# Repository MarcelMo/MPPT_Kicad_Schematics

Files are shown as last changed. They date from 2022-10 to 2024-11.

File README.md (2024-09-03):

Based on https://www.instructables.com/DIY-1kW-MPPT-Solar-Charge-Controller/
Since I wanted to be able to change the board layout and to test KiCad I decided to give this "conversion" a try.

- I removed the keyboard pullups, they are not needed when activating the internal pullup. And I prefer switching to ground anyway, so I can use 5V for the display and the keyboard.
- I changed the footprint of the screw terminals, since I did not find any other (trustworthy) 50A capable terminal. https://www.degson.com/content/details_552_880568.html
- Added JTAG interface
- Added a SD card and IIC socket, mainly for a RTC module. Should allow for much better offline logging.
- Switched to 1.27mm pitch smd connector. No need for 2.54mm. Just uses up too much space - on both sides of the board. Also added a few spare IOs and IIC.
- Fan driver transistor. ToDo: Maybe better switch +, and not GND. Although switching ground allows for more flexibility regarding fan voltage.
- Had to divide GND into GND and GND2, so I could add the GND copper bar to the schematics and the layout without getting too hacky... Found no better "KiCad way"
- 3D models are almost complete. SD card is not perfect.
- Switched to USB-C

3D VRML preview: https://marcelmo.github.io/MPPT_Kicad_Schematics/ (Thanks to https://easyw.github.io/vrm360/ )
MPPT_Charger_top_view
MPPT_Charger_bottom_view

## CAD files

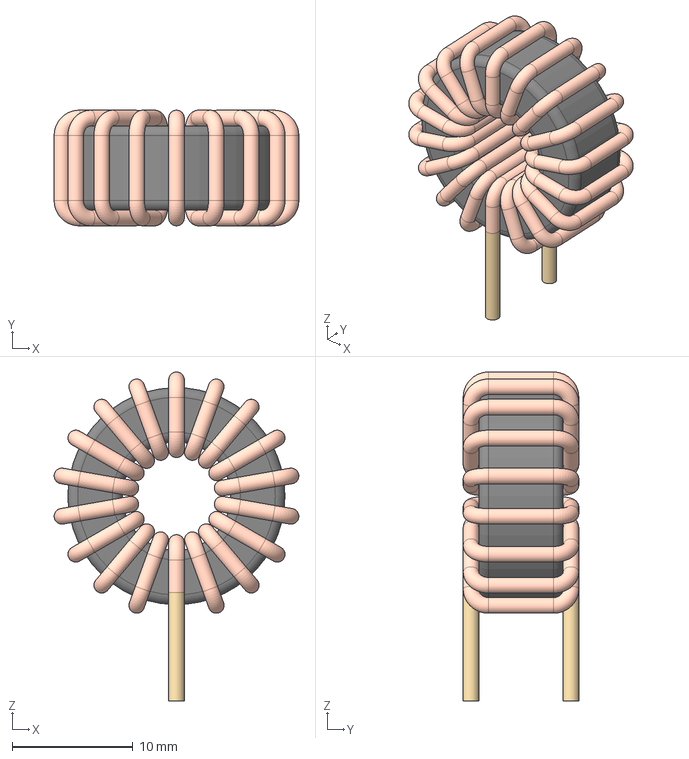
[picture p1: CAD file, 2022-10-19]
3D/torroid_inductor.step
20.3 x 9.60 x 27.3 mm

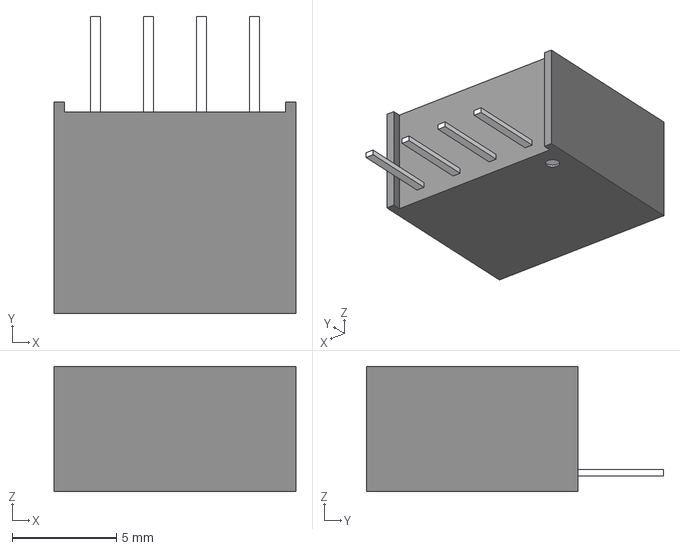
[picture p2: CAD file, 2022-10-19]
3D/B_S-1WR3.step
11.6 x 14.3 x 6.00 mm

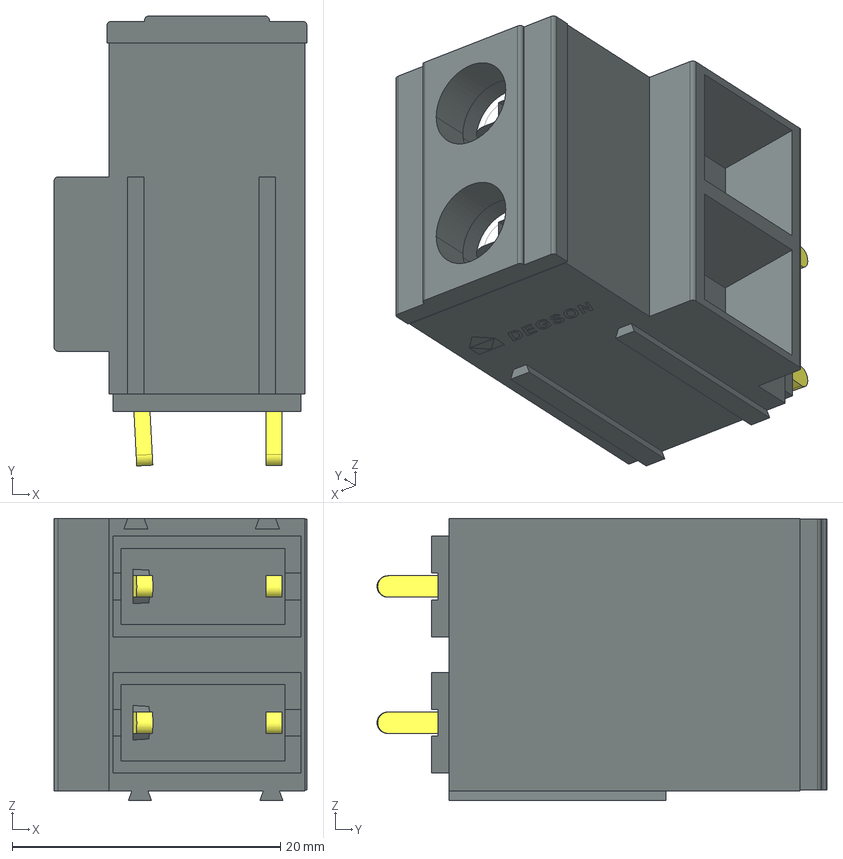
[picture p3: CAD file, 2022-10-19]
3D/DG135T-10.16-XXP-1Y-00A(H).step
18.9 x 33.6 x 21.0 mm

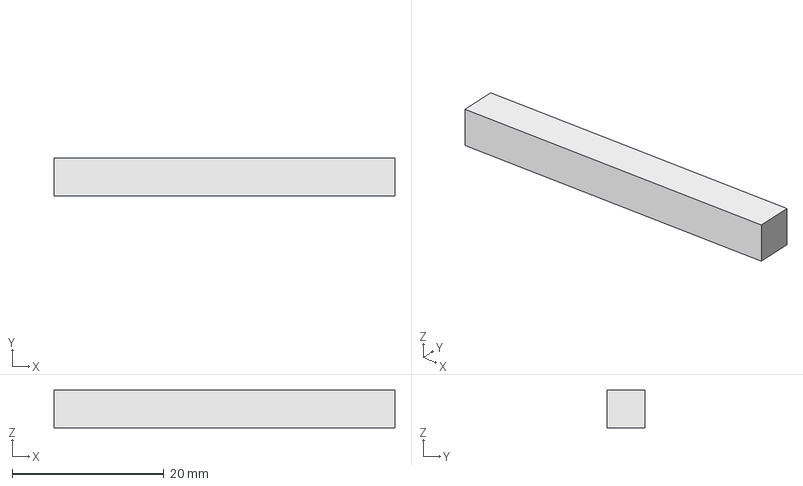
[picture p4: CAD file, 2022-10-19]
3D/bar.step
45.0 x 5.00 x 5.00 mm

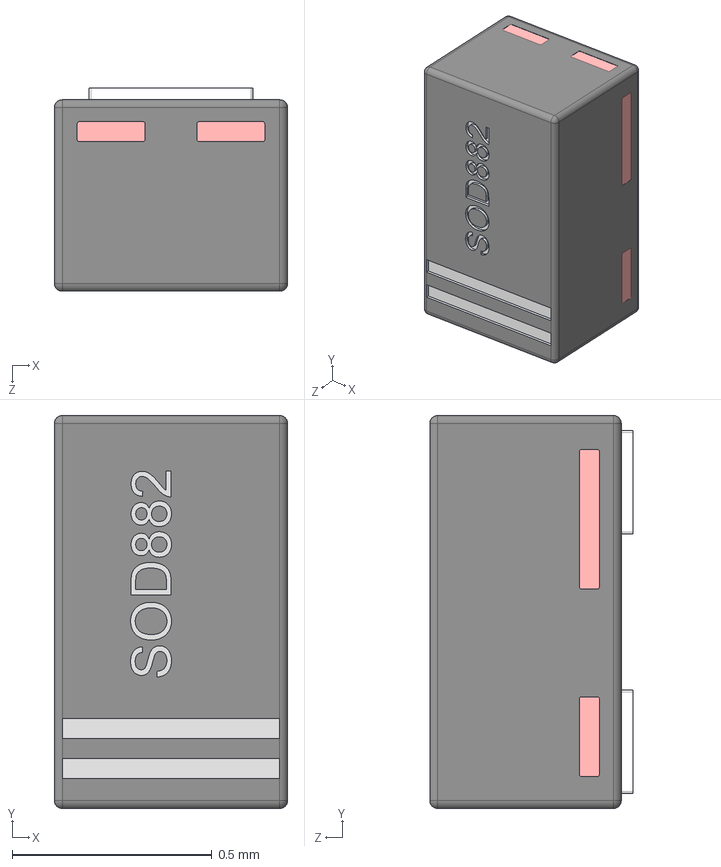
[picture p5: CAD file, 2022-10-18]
3D/SOD882-1.step
0.585 x 0.985 x 0.51 mm

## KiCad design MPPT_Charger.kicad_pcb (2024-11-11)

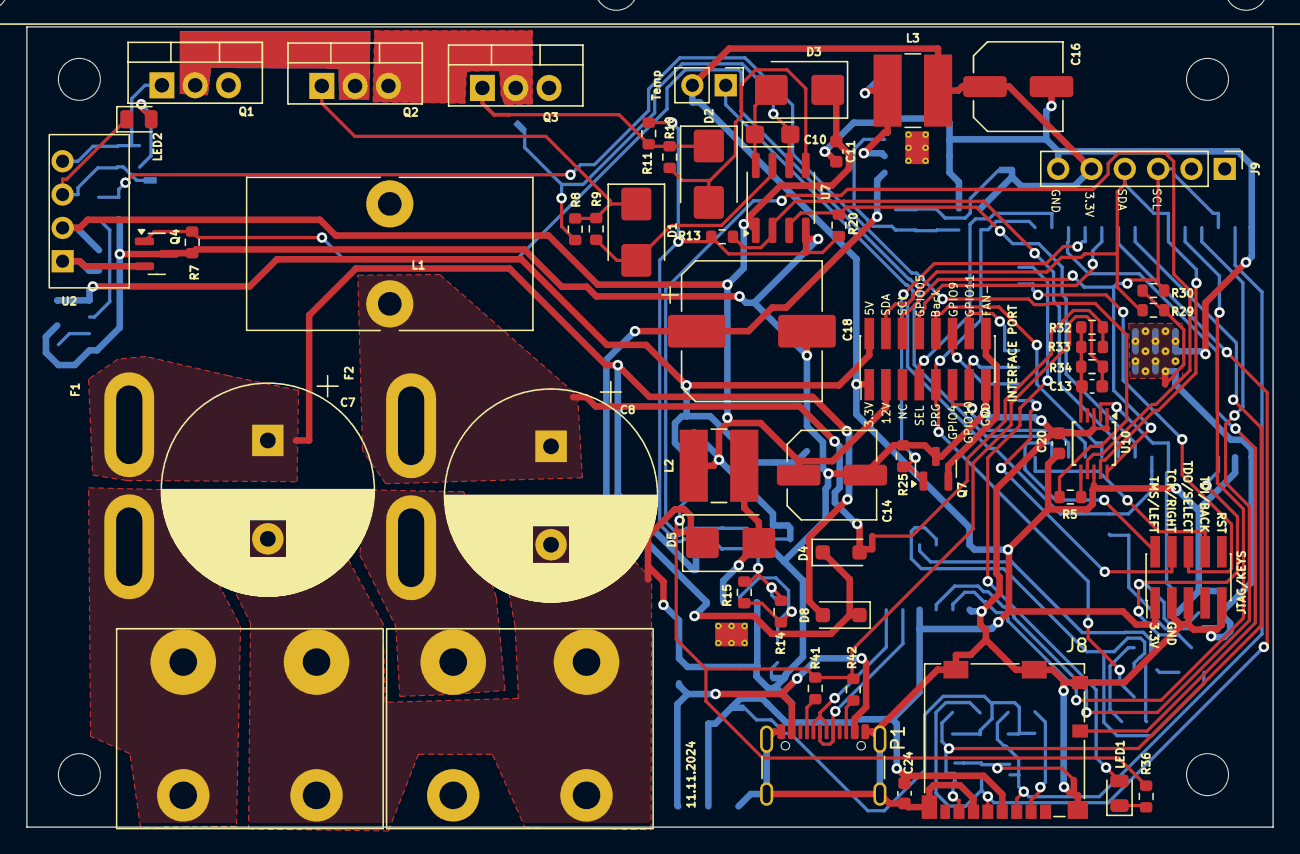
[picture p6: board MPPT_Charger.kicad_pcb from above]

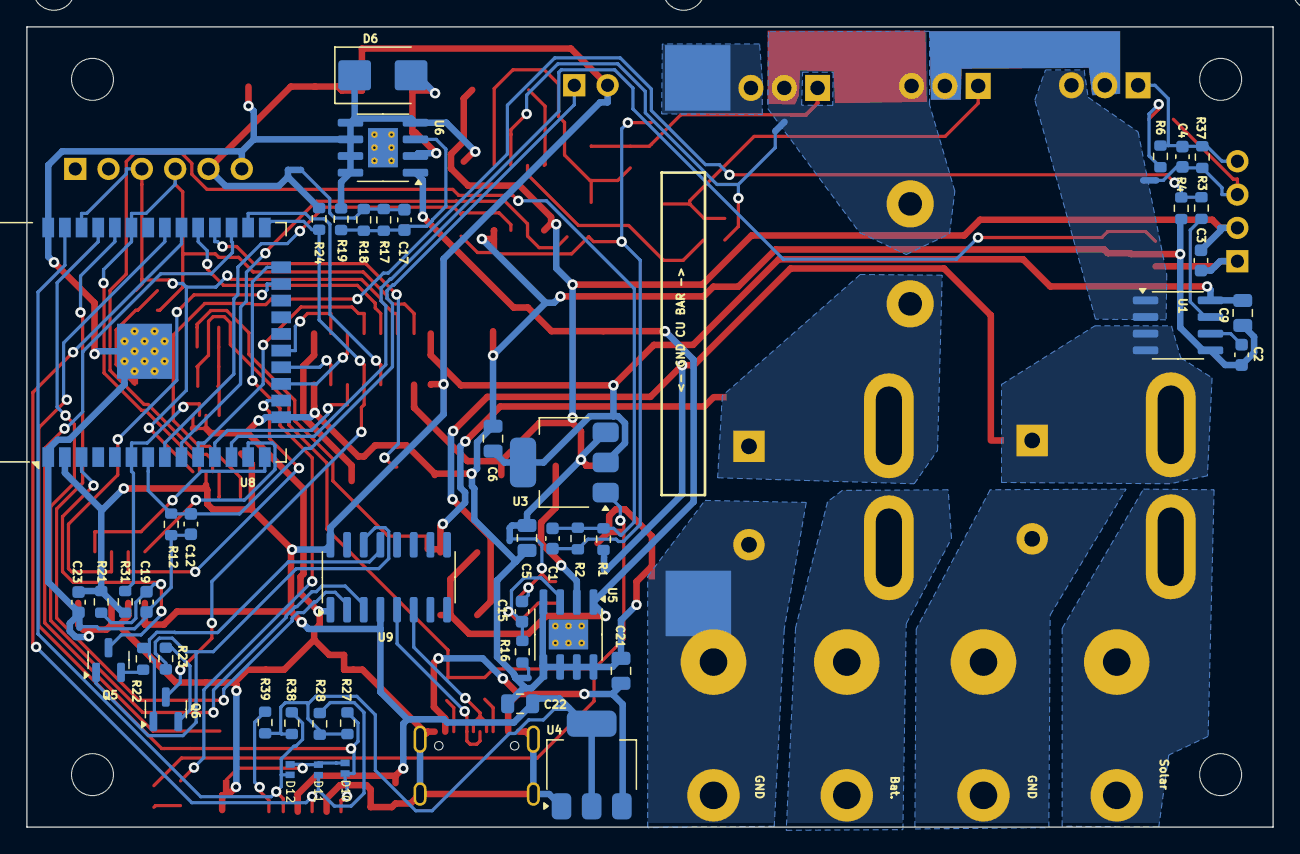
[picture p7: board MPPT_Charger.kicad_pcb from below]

Board: 2 copper layers, 95.0 x 61.0 mm, 128 parts (57 on the bottom side), 87 nets.

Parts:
C1, C3, C4, C11, C12, C13, C20, C23, C24: 100nF; C_0603_1608Metric
C2: 2.2uF; C_0603_1608Metric
C5, C6, C9, C21, C22: 4.7uF; C_0805_2012Metric
C7, C8: 470uF; CP_Radial_D16.0mm_P7.50mm
C10: 10uF; CP_EIA-3216-10_Kemet-I
C14, C16: 100uF; C_Elec_6.3x5.8
C15, C17: 33nF; C_0603_1608Metric
C18: 47uF; CP_Elec_10x10.5
C19: 470nF; C_0603_1608Metric
D1, D2, D3, D5, D6: SS310; D_SMB
D4, D8: 1N4007; D_SOD-123F
D10, D11, D12: LESD8D3.3CAT5G; SOD882D.kicad_mod
F1, F2: Fuse; Fuse_Blade_ATO_directSolder
HS1: Heatsink_Pad; Heatsink_125x35x50mm_3xFixationM3
J1: Solar; TerminalBlock_DEGSON_DG135T
J2: Battery; TerminalBlock_DEGSON_DG135T
J4: INTERFACE PORT; PinHeader_2x08_P1.27mm_Vertical_SMD
J6: JTAG/KEYS; PinHeader_2x05_P1.27mm_Vertical_SMD
J8: Micro_SD_Card_Det_Hirose_DM3AT; microSD_HC_Molex_104031-0811
J9: IIC RTC; PinHeader_1x06_P2.54mm_Vertical
JP1: Copper bar; COPPER_BAR
L1: 60uH; L_Toroid_Vertical_L21.6mm_W11.4mm_P7.62mm_Pulse_KM-3
L2, L3: 100uH; L_TracoPower_TCK-047_5.2x5.8mm
LED1, LED2: LED; LED_0805_2012Metric
NT1: GND to GND2; NetTie-2_SMD_Pad0.5mm
NT2, NT4, NT5, NT6, NT9, NT10, NT11, NT12, NT13, NT14, NT15, NT16, NT17: NetTie_2; NetTie-2_SMD_Pad0.5mm
NT3, NT7, NT8: NetTie-2_SMD_Pad0.5mm
P1: USB_C_Receptacle_USB2.0_16P; USB_C_Receptacle_GCT_USB4105-xx-A_16P_TopMnt_Horizontal
Q1, Q2: CSD19505KCS; TO-220-3_Vertical
Q3: CSD19505KCS; Package_TO_SOT_THTTO-220-3_Vertical_Insulated
Q4, Q7: Si2306; SOT-23
Q5, Q6: MMBT3904 1A; SOT-23
R1: 200k; R_0603_1608Metric
R2: 5.1k; R_0603_1608Metric
R3: 3.3k; R_0603_1608Metric
R4, R6, R7, R12, R13, R19, R20, R21, R22, R23, R24, R25, R27, R28, R29, R30, R31, R36, R37, R38, R39: 10k; R_0603_1608Metric
R5, R16, R34: 1k; R_0603_1608Metric
R8, R11: 100k; R_0603_1608Metric
R9, R10: 100; R_0603_1608Metric
R14, R15: 15k; R_0603_1608Metric
R17, R18: 33k; R_0603_1608Metric
R32, R33: 47k; R_0603_1608Metric
R35: 10k; PinHeader_1x02_P2.54mm_Vertical
R41, R42: 5.1K; R_0603_1608Metric
REF1, REF2, REF3, REF4: MountingHole_3.2mm_M3
U1: ACS712; SOIC-8_3.9x4.9mm_P1.27mm
U2: B1212S
U3: AMS1117-5.0; SOT-223-3_TabPin2
U4: AMS1117-3.3; SOT-223-3_TabPin2
U5, U6: XL7005A; SOIC-8-1EP_3.9x4.9mm_P1.27mm_EP2.29x3mm_ThermalVias
U7: IR2104; SOIC-8_3.9x4.9mm_P1.27mm
U8: ESP32; ESP32-WROOM-32
U9: CH340G; SOIC-16_3.9x9.9mm_P1.27mm
U10: ADS1015; TSSOP-10_3x3mm_P0.5mm

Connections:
+3.3V: C16.1, C20.2, C22.1, C23.2, C24.1, J4.1, J6.1, J8.4 (VDD), J9.5, L3.2, NT8.2, NT13.2, R21.1, R24.2, R31.1, R35.2, U4.2 (VO), U8.2 (VDD), U9.4 (V3), U9.16 (VCC), U10.8 (VDD)
+3.3V_LP: NT8.1, R27.1, R28.1, R38.1, R39.1
+5V: C6.1, C9.1, J4.2, U1.8 (VCC), U3.2 (VO)
+12V: C3.1, C5.1, C11.1, C14.1, D3.1 (Katode), J4.3, L2.2, NT12.1, U2.2 (VIN), U3.3 (VI), U7.1 (VCC)
A1: C13.1, R32.2, R33.2, R34.1, U10.5 (AIN1)
A2: R5.1, U10.6 (AIN2)
A3: C1.1, R1.2, R2.1, U10.7 (AIN3)
ADC_RDY: R31.2, U8.6 (IO34), U10.2 (ALERT/RDY)
BCCU: Q4.1 (G), R7.1, U8.12 (IO27)
DRV_IN: R13.1, U7.2 (IN), U8.9 (IO33)
DRV_SD: R20.1, U7.3 (~SD), U8.8 (IO32)
EN: C19.2, Q5.3 (C), R21.2, U8.3 (EN)
FAN: Q7.1 (G), R25.1, U8.28 (IO17)
FAN_GND: J4.16, Q7.2 (D)
GND: C2.2, C5.2, C6.2, C9.2, C11.2, C14.2, C16.2, C18.2, C20.1, C21.2, C22.2, C23.1, C24.2, D5.1 (Katode), D6.1 (Katode), J4.15, J6.3, J6.5, J6.9, J8.6 (VSS), J8.10 (DET_A), J8.11 (SHIELD), J9.6, NT1.2, NT7.2, NT11.1, NT14.2, NT15.2, NT16.2, NT17.2, P1.A1 (GND), P1.A12 (GND), P1.B1 (GND), P1.B12 (GND), P1.S1 (SHIELD), Q4.3 (S), Q7.3 (S), R4.2, R7.2, R19.2, R25.2, U1.5 (GND), U4.1 (GND), U5.4 (EN), U5.5 (GND), U5.6 (GND), U5.7 (GND), U5.8 (GND), U6.4 (EN), U6.5 (GND), U6.6 (GND), U6.7 (GND), U6.8 (GND), U7.4 (COM), U8.1 (GND), U8.15 (GND), U8.38 (GND), U8.39 (GND), U9.1 (GND), U10.1 (ADDR), U10.3 (GND)
GND2: C7.2, C8.2, J1.2, J2.2, JP1.1 (A), NT1.1
GND_J4: NT14.1, R29.1, R30.1
GND_LP: C13.2, NT7.1, R34.2, R36.1, R41.2, R42.2, U3.1 (GND)
GND_U8: C12.2, C19.1, NT15.1, R12.2
GPIO4: J4.7, U8.26 (IO4)
GPIO5: J4.8, U8.29 (IO5)
GPIO9: J4.12, U8.17 (SHD/SD2)
GPIO10: J4.13, U8.18 (SWP/SD3)
GPIO11: J4.14, U8.19 (SCS/CMD)
GPIO25: J4.10, U8.10 (IO25)
GPIO26: J4.11, U8.11 (IO26)
KEY_BACK: J6.8, U8.14 (IO12)
KEY_LEFT: J6.2, U8.13 (IO14)
KEY_RIGHT: J6.4, U8.16 (IO13)
KEY_SELECT: J6.6, U8.23 (IO15)
unnamed: C1.2, NT17.1, R2.2, R11.2, R13.2, R20.2
unnamed: C7.1, F1.2, NT2.2, U1.3 (IP-), U1.4 (IP-)
unnamed: C8.1, F2.2, L1.2, NT6.1
unnamed: C15.1, NT12.2, R14.1, R15.1
unnamed: C17.1, NT13.1, R17.1, R18.1
unnamed: D1.2 (Anode), R9.1, U7.7 (HO)
unnamed: D1.1 (Katode), Q2.1 (G), R8.1, R9.2
unnamed: D2.2 (Anode), R10.1, U7.5 (LO)
unnamed: D2.1 (Katode), Q3.1 (G), R10.2, R11.1
unnamed: C10.1, D3.2 (Anode), U7.8 (VB)
unnamed: D4.2 (A), NT6.2, NT10.1
unnamed: C18.1, D4.1 (K), D8.1 (K), U5.1 (VIN), U6.1 (VIN)
unnamed: D5.2 (Anode), L2.1, U5.2 (SW)
unnamed: D6.2 (Anode), L3.1, U6.2 (SW)
unnamed: D8.2 (A), NT2.1, NT9.1
unnamed: D10.1 (A1), D11.1 (A1), D12.1 (A1), NT16.1
unnamed: F1.1, J1.1
unnamed: F2.1, J2.1
unnamed: J8.2 (DAT3/CD), R39.2
unnamed: JP1.2 (B), Q3.3 (S)
unnamed: LED1.2 (A), U8.24 (IO2)
unnamed: LED1.1 (K), R36.2
unnamed: LED2.2 (A), R6.1
unnamed: C4.2, LED2.1 (K), NT3.2, R37.1, U2.3 (GND2)
unnamed: NT9.2, R1.1
unnamed: NT10.2, R32.1, R33.1
unnamed: NT11.2, R16.2
unnamed: P1.A5 (CC1), R41.1
unnamed: P1.B5 (CC2), R42.1
unnamed: NT5.2, Q1.2 (D), Q2.2 (D)
unnamed: C4.1, Q1.1 (G), R6.2, R37.2, U2.4 (VOUT)
unnamed: NT3.1, Q1.3 (S), U1.1 (IP+), U1.2 (IP+)
unnamed: L1.1, NT4.2, Q2.3 (S), Q3.2 (D)
unnamed: C3.2, Q4.2 (D), U2.1 (GND)
unnamed: Q5.2 (B), R22.2
unnamed: Q5.1 (E), R23.1, U9.14 (~RTS)
unnamed: Q6.2 (B), R23.2
unnamed: Q6.1 (E), R22.1, U9.13 (~DTR)
unnamed: R3.2, R4.1, R5.2
unnamed: C2.1, U1.6 (FILTER)
unnamed: R3.1, U1.7 (VIOUT)
unnamed: C15.2, R14.2, R15.2, R16.1, U5.3 (FB)
unnamed: C17.2, R17.2, R18.2, R19.1, U6.3 (FB)
unnamed: C10.2, NT4.1, R8.2, U7.6 (VS)
unnamed: P1.A6 (D+), P1.B6 (D+), U9.5 (UD+)
unnamed: P1.A7 (D-), P1.B7 (D-), U9.6 (UD-)
PRG: J4.9, Q6.3 (C), R24.1, U8.25 (IO0)
RX: U8.34 (RXD0/IO3), U9.2 (TXD)
SCL: J4.6, J9.3, R30.2, U8.36 (IO22), U10.10 (SCL)
SDA: J4.4, J9.4, R29.2, U8.33 (IO21), U10.9 (SDA)
SD_CLK: D11.2 (A2), J8.5 (CLK), R28.2, U8.30 (IO18)
SD_DET_B: J8.9 (DET_B), U8.27 (IO16)
SD_MISO: D10.2 (A2), J8.7 (DAT0), R27.2, U8.31 (IO19)
SD_MOSI: D12.2 (A2), J8.3 (CMD), R38.2, U8.37 (IO23)
TX: U8.35 (TXD0/IO1), U9.3 (RXD)
Utemp: C12.1, R12.1, R35.1, U8.7 (IO35)
VBUS: C21.1, P1.A4 (VBUS), P1.A9 (VBUS), P1.B4 (VBUS), P1.B9 (VBUS), U4.3 (VI)

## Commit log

2022-10-11 MPPT Charger
    [Projekt.kicad_pcb, Projekt.kicad_sch]
2022-10-12 Schaltplan fertig ?
    [Projekt.kicad_sch]
2022-10-14 So gut wie fertig ... ?
    [Projekt.kicad_pcb, Projekt.kicad_sch]
2022-10-15 Leiterbahnen verstärkt
    [Projekt.kicad_pcb, Projekt.kicad_sch]
2022-10-16 Eigentlich okay...
    [Projekt.kicad_pcb, Projekt.kicad_sch]
2022-10-16 Fehlerhafte Pads entfernt und in Footprint eingebaut
    [Projekt.kicad_pcb, Projekt.kicad_sch]
2022-10-17 SD + RTC
    [Projekt.kicad_pcb, Projekt.kicad_sch]
2022-10-19 3D Modelle und Footprints vervollständigt
    [B_S-1WR3.step, DG135T-10.16-XXP-1Y-00A(H).step, Projekt.kicad_pcb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]
2022-10-20 Fuse Holder 3D Modell
    [Mini Blade Fuse Holder.step]
2022-10-21 Sieht ganz gut aus...
    [Projekt.kicad_pcb, Projekt.kicad_sch]
2022-10-22 RTC 3D Model
    [Projekt.kicad_pcb]
2022-10-22 Project renamed
    [MPPT_Charger.kicad_pcb, MPPT_Charger.kicad_sch]
2022-10-23 Heatsink and insulation ToDo: Smaller heatsink
    [MPPT_Charger.kicad_pcb, MPPT_Charger.kicad_sch, TO-220 Device with Insulating Hardware.step]
2022-10-24 Heat sink size corrected
    [MPPT_Charger.kicad_pcb]
2022-10-25 Footprint C+R changed to 0603 where possible
    [MPPT_Charger.kicad_pcb, MPPT_Charger.kicad_sch]
2022-10-25 Done ?
    [MPPT_Charger.kicad_pcb]
2022-10-25 footprint for ADS1115 updated
    [MPPT_Charger.kicad_pcb]
2022-11-02 Holes were too small
2022-11-02 Footprint updates for some parts (mainly too small drill holes for screw terminal and larger capacitors)
    [MPPT_Charger.kicad_pcb, MPPT_Charger.kicad_sch]
2022-11-03 Footprint for 470uF was too small Some more minor changes
    [MPPT_Charger.kicad_pcb, MPPT_Charger.kicad_sch]
2022-11-03 Some parts ref was unreadable
    [MPPT_Charger.kicad_pcb]
2022-11-04 SD card pins were wrong https://github.com/MarcelMo/MPPT_Kicad_Schematics/issues/1
    [MPPT_Charger.kicad_pcb, MPPT_Charger.kicad_sch]
2022-11-05 Degson terminal 3D model path updated
    [MPPT_Charger.kicad_pcb]
2022-11-05 VRML preview in browser
    using three.js and github pages and code by https://easyw.github.io/vrm360/
    Switched project to public to use Github Pages
2022-12-20 Some missing copper and minor changes
    [MPPT_Charger.kicad_pcb, MPPT_Charger.kicad_sch]
2024-09-01 KICAD V8
    [MPPT_Charger.kicad_pcb, MPPT_Charger.kicad_sch]
2024-09-03 Reworked layout. Changed a few pins. Double power transistors removed. Traces would not be able to support the amperage anyway.
    [MPPT_Charger.kicad_pcb, MPPT_Charger.kicad_sch]
2024-09-23 Some manual corrections, and some too small footprints updated.
    [MPPT_Charger.kicad_pcb, MPPT_Charger.kicad_sch]
2024-10-04 A lot of updates. Used net classes. Changed some footprints and 3D models. Corrected pinouts of connectors. Changed pins for keyboard to use same pins as JTAG connector, seemed like a useful double u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
    [MPPT_Charger.kicad_pcb, MPPT_Charger.kicad_sch]
2024-10-16 Some Zones were wrong/missing
    [MPPT_Charger.kicad_pcb, MPPT_Charger.kicad_sch]
2024-10-27 USB-C corrected- I hope Moved more parts topside again
    [MPPT_Charger.kicad_pcb, MPPT_Charger.kicad_sch]
2024-11-11 RxD TxD were wrong :-(
    [MPPT_Charger.kicad_pcb, MPPT_Charger.kicad_sch]
2025-10-13 Kicad 9.0 + minor changes (some "power" vias)
